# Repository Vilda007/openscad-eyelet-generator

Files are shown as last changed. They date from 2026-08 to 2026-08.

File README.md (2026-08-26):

# OpenSCAD Eyelet Generator

A parametric eyelet generator for 3D printing, designed for outdoor and camping gear. Compatible with [MakerWorld's Parametric Model Maker (PMM)](https://makerworld.com) — users can customize parameters directly on the model page.

## Eyelet Types

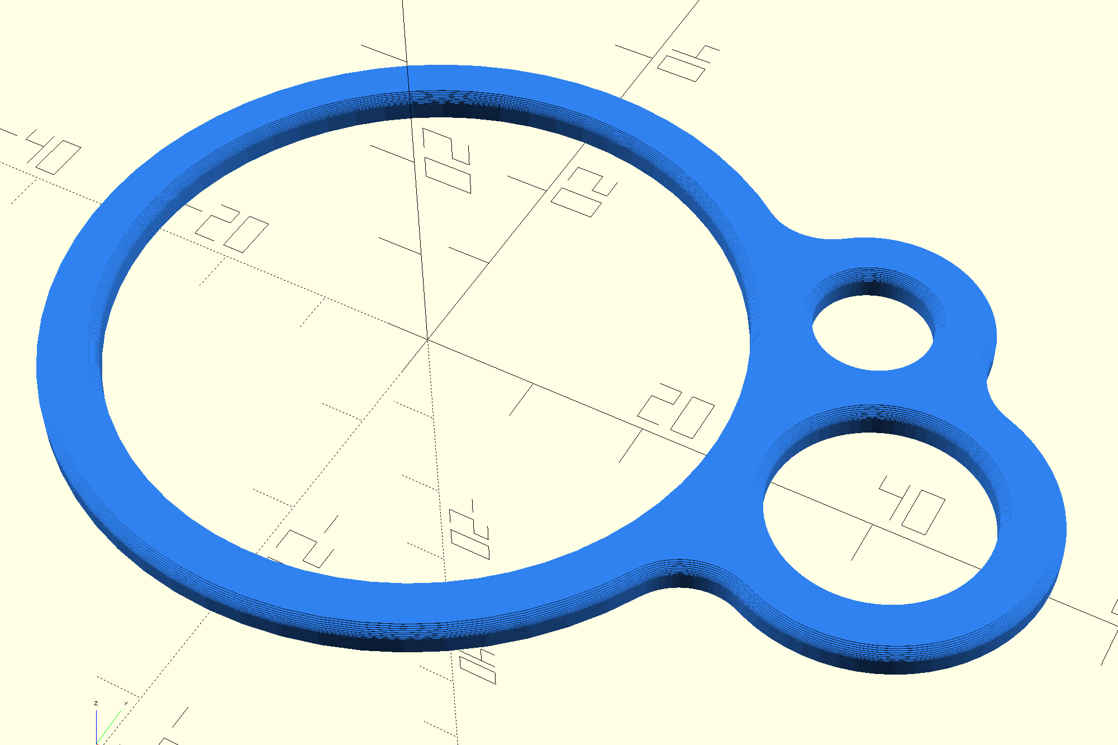
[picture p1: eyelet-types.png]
Eyelet Types


| # | Type | Description |
|---|---|---|
| 1 | **Simple O** | Single ring with inner and outer diameter |
| 2 | **Simple 8** | Two rings side by side, outer edges touching |
| 3 | **Double O Egg** | Two rings inside a smooth egg-shaped envelope |
| 4 | **Snowman** | Three rings in a row, outer edges touching |
| 5 | **Triangle** | Three rings at triangle vertices |
| 6 | **Joined 8** | Two rings with connected inner holes |
| 7 | **Joined Snowman** | Three rings in a row with connected inner holes |
| 8 | **Simple D** | Half ring with a flat closing wall (D-shape) |
| 9 | **Double D** | Ring split in half by a center dividing wall |
| 10 | **Simple S** | S-shaped curve from two partial-circle arcs |

### Printed Examples

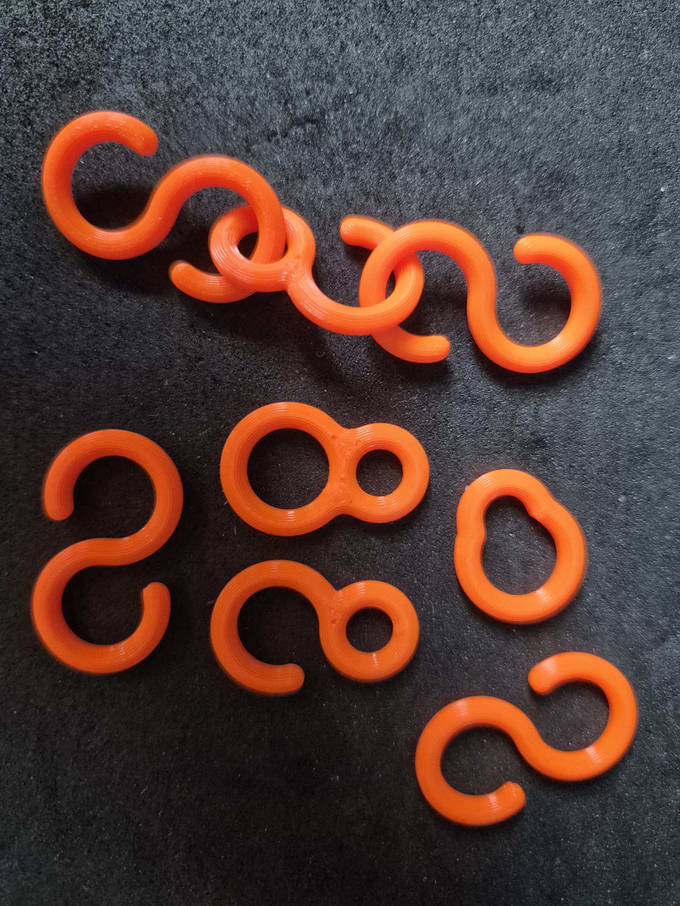
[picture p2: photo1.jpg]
Printed Eyelet 1


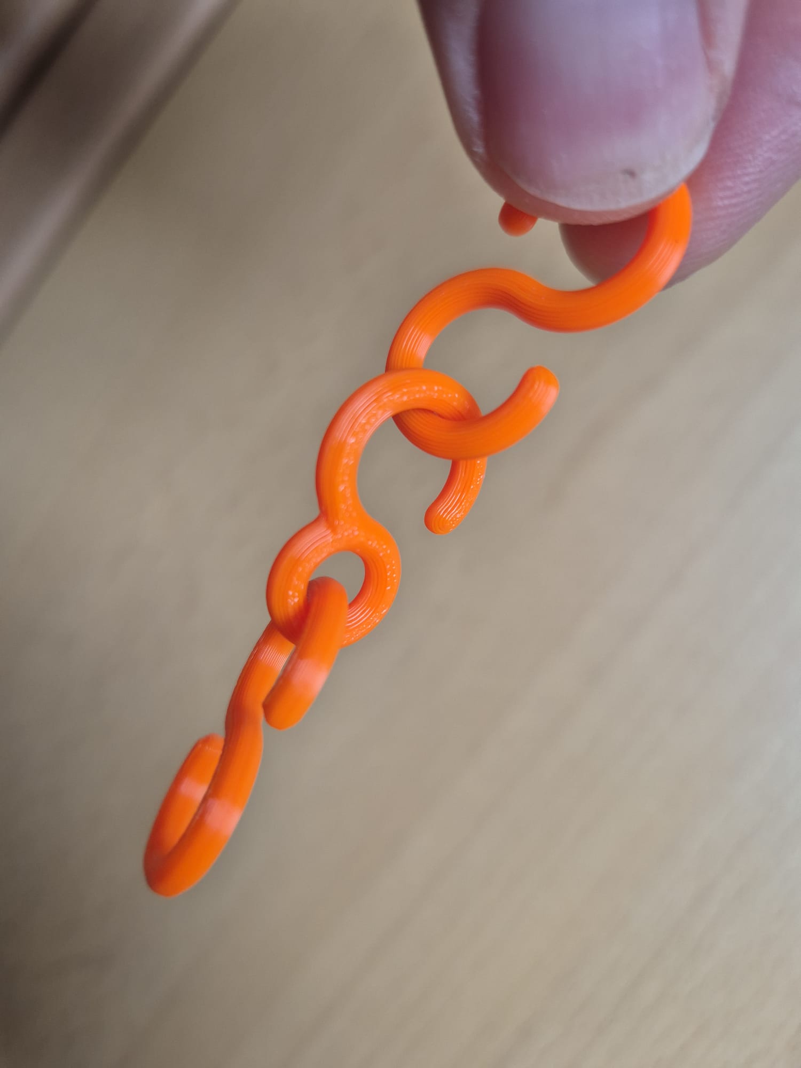
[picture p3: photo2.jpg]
Printed Eyelet 2


## Parameters

### Dimensions
- **Wall thickness** (1–10 mm) — thickness of the ring wall
- **Height** (1–10 mm) — extrusion height
- **Base inner diameter** (1–150 mm) — inner diameter of the primary ring
- **Second inner diameter** (1–150 mm) — inner diameter of the second ring
- **Third inner diameter** (1–150 mm) — inner diameter of the third ring

### 3D Edge Filleting
- **Bottom edge radius** (0–10 mm) — rounds the bottom edge
- **Top edge radius** (0–10 mm) — rounds the top edge
- **Fillet resolution** (1–30 layers) — smoothness of edge rounding

### 2D Smoothing
- **Connection fillet radius** (0–10 mm) — rounds V-junctions where rings meet

### S Shape — Hook 1 & Hook 2
- **Percentage of circle** (70–100%) — controls how much of the circle each S-hook covers

### Color
- Color picker (hex string) — visible in MakerWorld PMM

## Usage

### Local (OpenSCAD)
1. Open `eyelet-generator.scad` in [OpenSCAD](https://openscad.org)
2. Use the Customizer panel (Window → Customizer) to adjust parameters
3. Press F5 for preview, F6 for full render
4. Export STL/3MF for 3D printing

### MakerWorld PMM
1. Upload `eyelet-generator.scad` to [MakerWorld](https://makerworld.com)
2. Users click "Customize" on the model page
3. Parameters appear as interactive sliders and dropdowns
4. Users download ready-to-print 3MF/STL

## Technical Details

- **OpenSCAD version:** 2021.01+
- **No external dependencies** — uses only built-in OpenSCAD functions
- **PMM-compatible** — follows OpenSCAD Customizer conventions with `// [min:step:max]` sliders and `// [value:Label]` dropdowns

### Key Techniques

- **Concave fillet** (`offset(-r) → offset(+r)`) — rounds V-junctions where rings touch
- **Convex fillet** (`offset(+r) → offset(-r)`) — rounds outward-pointing corners
- **Layered edge fillet** — independent top/bottom 3D edge rounding via layered `linear_extrude` with cosine-eased `offset()`
- **Triangle layout** — ring positions computed via law of cosines from pairwise distances
- **S-shape** — built as `hull()` of circles along arc paths, creating a tube around the curve

## License

CC-BY-SA-4.0

## Authors

- **Vilda** (Vilém Kužel) — design and geometry
- **Klepeto** — implementation and testing

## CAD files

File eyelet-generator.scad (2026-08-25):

// =====================================================================
// Eyelet Generator — Parametric Model Maker (PMM) Compatible
// Generates various eyelet types for outdoor & camping gear
//
// Author: Vilda (Vilém Kužel) & Klepeto
// License: CC-BY-SA-4.0
// Repository: https://github.com/vildakuzel/openscad-eyelet-generator
// =====================================================================

/* [Eyelet Type] */
// Select eyelet type
eyelet_type = 1; // [1:Simple O, 2:Simple 8, 3:Double O Egg, 4:Snowman, 5:Triangle, 6:Joined 8, 7:Joined Snowman, 8:Simple D, 9:Double D, 10:Simple S]

/* [Dimensions] */
// Wall thickness — thickness of the eyelet ring wall
wall_thickness = 3; // [1:1:10]

// Height — extrusion height of the eyelet
height = 3; // [1:1:10]

// Base inner diameter — inner diameter of the primary ring
base_o_diameter = 15; // [1:1:150]

// Second inner diameter — inner diameter of the second ring (Simple 8, Double O Egg, Snowman, Triangle, Joined 8, Simple S)
second_o_diameter = 5; // [1:1:150]

// Third inner diameter — inner diameter of the third ring (Snowman, Triangle)
third_o_diameter = 10; // [1:1:150]

/* [3D Edge Filleting] */
// Bottom edge radius — rounds the bottom edge of the eyelet
bottom_edge_fillet = 0; // [0:0.1:10]

// Top edge radius — rounds the top edge of the eyelet
top_edge_fillet = 0; // [0:0.1:10]

// Fillet resolution — number of layers for edge rounding (higher = smoother, slower)
fillet_steps = 10; // [1:1:30]

/* [2D Smoothing] */
// Connection fillet radius — rounds V-junctions where rings meet
fillet_radius = 2; // [0:0.1:10]

/* [S Shape — Hook 1] */
// Hook 1 — percentage of a full circle (larger = more closed loop)
s_arc_1_pct = 83; // [70:1:100]

/* [S Shape — Hook 2] */
// Hook 2 — percentage of a full circle (larger = more closed loop)
s_arc_2_pct = 83; // [70:1:100]

/* [Color] */
// Eyelet color
eyelet_color = "#2F80ED"; // color

/* [Hidden] */
$fn = 64;

// Derived radius values
inner_radius = base_o_diameter / 2;
outer_radius = inner_radius + wall_thickness;

second_inner_radius = second_o_diameter / 2;
second_outer_radius = second_inner_radius + wall_thickness;

third_inner_radius = third_o_diameter / 2;
third_outer_radius = third_inner_radius + wall_thickness;

// Ring center offsets (outer edges touching)
ring_offset_1 = inner_radius + wall_thickness + second_inner_radius;
ring_offset_2 = ring_offset_1 + second_inner_radius + wall_thickness + third_inner_radius;

// Joined offsets (centers closer, inner holes connected)
joined_offset_1 = inner_radius + second_inner_radius - wall_thickness;
joined_offset_2 = joined_offset_1 + second_inner_radius + third_inner_radius - wall_thickness;

// Triangle layout — pairwise distances and vertex coordinates
d12 = inner_radius + wall_thickness + second_inner_radius;
d13 = inner_radius + wall_thickness + third_inner_radius;
d23 = second_inner_radius + wall_thickness + third_inner_radius;
tri_x = (d12*d12 + d13*d13 - d23*d23) / (2 * d12);
tri_y = sqrt(max(0, d13*d13 - tri_x*tri_x));

// =====================================================================
// Geometry Helpers
// =====================================================================

// Smooth concave V-junctions by shrinking then growing the shape.
// Use on union() of touching circles to round the inner V where they meet.
// offset(-r) cuts the V tip, offset(+r) restores with a rounded curve.
module smooth_concave(r) {
    if (r > 0) { offset(r = -r) offset(r = r) children(); }
    else { children(); }
}

// Smooth convex sharp tips by growing then shrinking the shape.
// Use on shapes with outward-pointing corners (e.g. D-shape junctions).
// offset(+r) rounds the tip outward, offset(-r) shrinks back to size.
module smooth_convex(r) {
    if (r > 0) { offset(r = r) offset(r = -r) children(); }
    else { children(); }
}

// Simple ring (annulus) — outer cylinder minus inner cylinder
module ring(r_outer, r_inner, h) {
    difference() {
        cylinder(h = h, r = r_outer);
        translate([0, 0, -1]) cylinder(h = h + 2, r = r_inner);
    }
}

// Layered extrusion with independent top and bottom edge fillets.
// Takes a 2D children() shape and extrudes it with rounded top/bottom edges.
// Uses layered linear_extrude with cosine-eased 2D offset() per layer.
module stepped_fillet_extrusion(h, bot_r, top_r, steps) {
    safe_bot = min(bot_r, h / 2);
    safe_top = min(top_r, h / 2);
    mid_h = h - safe_bot - safe_top;

    if (safe_bot == 0 && safe_top == 0) {
        linear_extrude(h) children();
    } else {
        // Bottom fillet — profile shrinks toward the bottom edge
        if (safe_bot > 0)
            for (i = [0 : steps - 1]) {
                z_start = i * safe_bot / steps;
                z_end = z_start + safe_bot / steps;
                z_mid = (z_start + z_end) / 2;
                t = z_mid / safe_bot;
                off = safe_bot * (1 - sin(t * 90));
                translate([0, 0, z_start])
                    linear_extrude(safe_bot / steps + 0.001)
                        offset(r = -off) children();
            }
        // Middle zone — full profile, no offset
        if (mid_h > 0)
            translate([0, 0, safe_bot])
                linear_extrude(mid_h + 0.001) children();
        // Top fillet — mirrored bottom fillet for convex rounding
        if (safe_top > 0)
            mirror([0, 0, 1])
                translate([0, 0, -h])
                for (i = [0 : steps - 1]) {
                    z_start = i * safe_top / steps;
                    z_end = z_start + safe_top / steps;
                    z_mid = (z_start + z_end) / 2;
                    t = z_mid / safe_top;
                    off = safe_top * (1 - sin(t * 90));
                    translate([0, 0, z_start])
                        linear_extrude(safe_top / steps + 0.001)
                            offset(r = -off) children();
                }
    }
}

// Generate points along a circular arc (used for S-shape polygon paths)
function arc_points(center, r, start_angle, direction, sweep, n = 48) =
    [for (i = [0 : n]) let(a = start_angle + direction * sweep * i / n)
        [center[0] + r * cos(a), center[1] + r * sin(a)]];

// =====================================================================
// Eyelet Types
// =====================================================================

// Type 1: Simple O — a single ring with inner and outer diameter
module simple_o_eyelet() {
    stepped_fillet_extrusion(height, bottom_edge_fillet, top_edge_fillet, fillet_steps)
    difference() { circle(r = outer_radius); circle(r = inner_radius); }
}

// Type 2: Simple 8 — two rings side by side, outer edges touching
// Connection fillet smooths the V-junction on the outer perimeter
module simple_8_eyelet() {
    stepped_fillet_extrusion(height, bottom_edge_fillet, top_edge_fillet, fillet_steps)
    difference() {
        smooth_concave(fillet_radius)
        union() {
            circle(r = outer_radius);
            translate([ring_offset_1, 0]) circle(r = second_outer_radius);
        }
        circle(r = inner_radius);
        translate([ring_offset_1, 0]) circle(r = second_inner_radius);
    }
}

// Type 3: Double O Egg — two rings inside a smooth egg-shaped envelope
// hull() creates a tangent bridge between the two outer circles
module double_o_egg_eyelet() {
    stepped_fillet_extrusion(height, bottom_edge_fillet, top_edge_fillet, fillet_steps)
    difference() {
        hull() {
            circle(r = outer_radius);
            translate([ring_offset_1, 0]) circle(r = second_outer_radius);
        }
        circle(r = inner_radius);
        translate([ring_offset_1, 0]) circle(r = second_inner_radius);
    }
}

// Type 4: Snowman — three rings in a row, outer edges touching
module snowman_eyelet() {
    stepped_fillet_extrusion(height, bottom_edge_fillet, top_edge_fillet, fillet_steps)
    difference() {
        smooth_concave(fillet_radius)
        union() {
            circle(r = outer_radius);
            translate([ring_offset_1, 0]) circle(r = second_outer_radius);
            translate([ring_offset_2, 0]) circle(r = third_outer_radius);
        }
        circle(r = inner_radius);
        translate([ring_offset_1, 0]) circle(r = second_inner_radius);
        translate([ring_offset_2, 0]) circle(r = third_inner_radius);
    }
}
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

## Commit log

2026-08-25 Initial commit: OpenSCAD Eyelet Generator with 10 parametric eyelet types
    - Simple O, Simple 8, Double O Egg, Snowman, Triangle
    - Joined 8, Joined Snowman, Simple D, Double D, Simple S
    - Independent top/bottom 3D edge fillets
    - 2D connection fillet smoothing
    - S-shape hook percentage parameter (70-100%)
    - MakerWorld PMM compatible
    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
    [eyelet-generator.scad]
2026-08-25 Fix S-shape curve radius: add wall_thickness/2 offset so inner edge matches base_o_diameter
    [eyelet-generator.scad]
2026-08-26 Add photos of 3D printed eyelets
    Two photos showing printed eyelet examples.
2026-08-26 Add printed eyelet photos to README
